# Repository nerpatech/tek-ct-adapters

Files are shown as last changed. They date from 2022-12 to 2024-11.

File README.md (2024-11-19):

# TO-252 Test Fixture Adapter for Tektronix Curve Tracers

Test fixture adapter for Tektronix curve tracers. Fits Tek 576, Tek 577 test fixtures, possibly others.

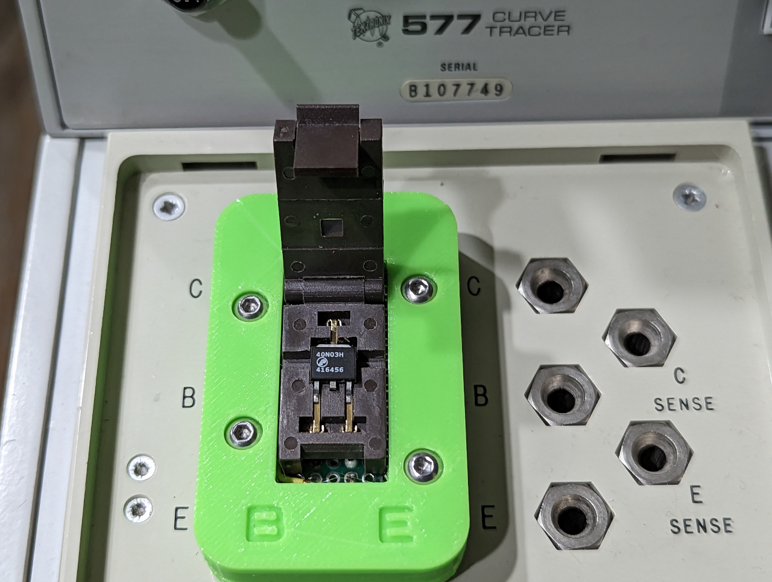
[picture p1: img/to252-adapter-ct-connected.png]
TO-252 adapter plugged into the curve tracer


## Bill Of Materials

| Item | Qty | Source |
| --- | --- | --- |
| Prototype Board, 5x7mm, 0.1 in. hole pitch | 1 |
| 4 mm RC-style banana plugs | 3 |
| 6mm silicone rubber feet | 2 |
| TO-252 burn-in adapter | 1 |
| M3x8mm button head socket screws | 4 |
| M3 nuts | 4 |

## Tools

Drill Press*, 3/16" drill bit*, 3D printer, any rigid filament (PETG, PLA, ABS, etc.), soldering iron, hookup wire.

## Assembly

Printed part models are in 'STL/' folder.
Please also check the 'img/' folder for assembly pictures.

1. Print bottom, middle, and top pieces, as well as two jigs. Printing parameters: 0.6mm or smaller nozzle, 0.3mm or lower
layer height. 

2. Using the drill jig find holes that can be used as pilots for 3mm screws on the prototype board, mark them, remove the jig, then drill 3mm holes where marked.

3. Screw the drill jig to the board, drill 3/16" holes for the banana plugs.

4. Cut the excess material. A drill jig can be used to make the clean edge.

5. Insert banana plugs as shown. Check the height protruding from the other side, should be 1mm*. A leveling jig can be used.

6. Insert* and solder TO252 test socket as shown. Connect the socket pins to the banana plugs.

7. Assemble 3 printed pieces and PCB as shown.

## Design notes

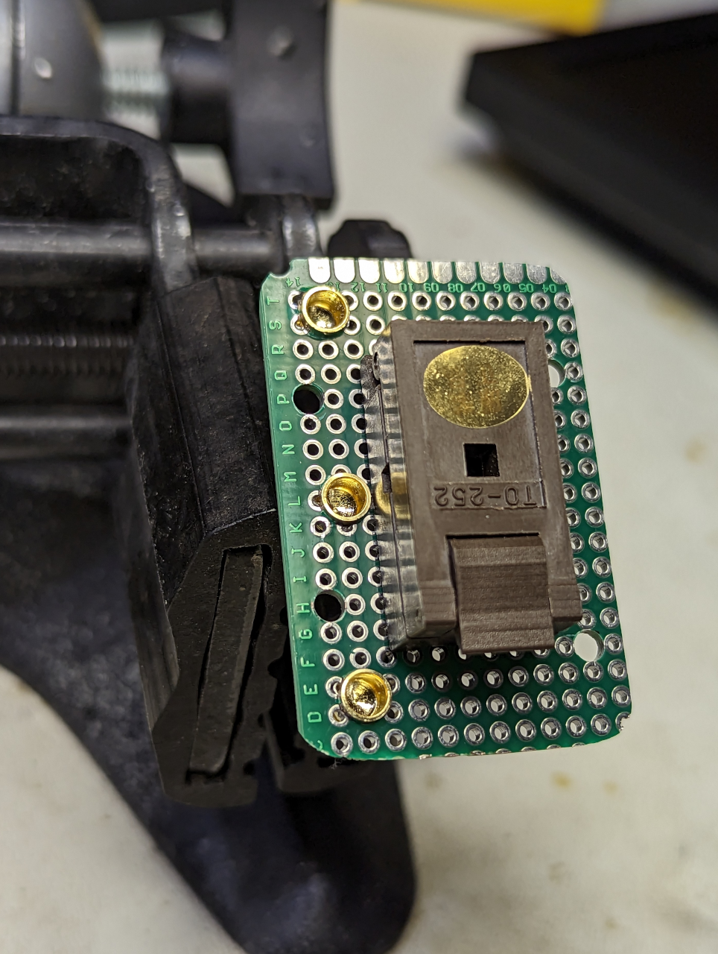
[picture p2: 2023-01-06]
img/to252-socket-try.png

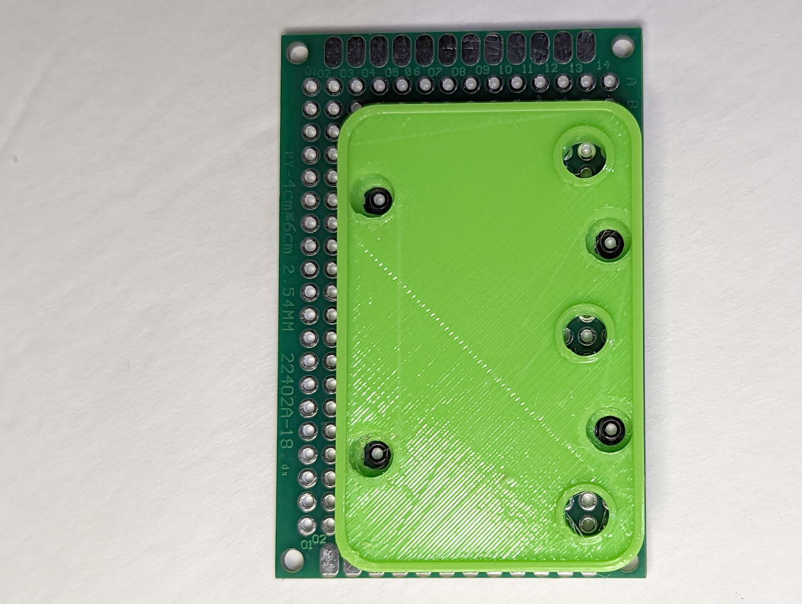
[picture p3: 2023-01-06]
img/to252-drill-jig-and-pcb-aligned.png

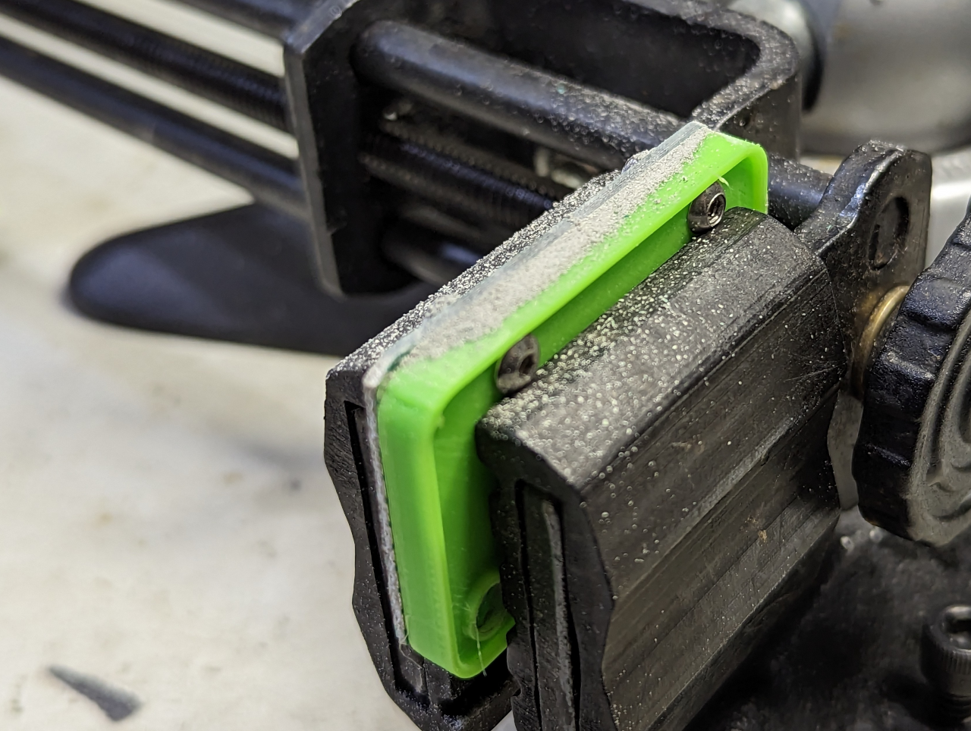
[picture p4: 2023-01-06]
img/to252-pcb-sized.png

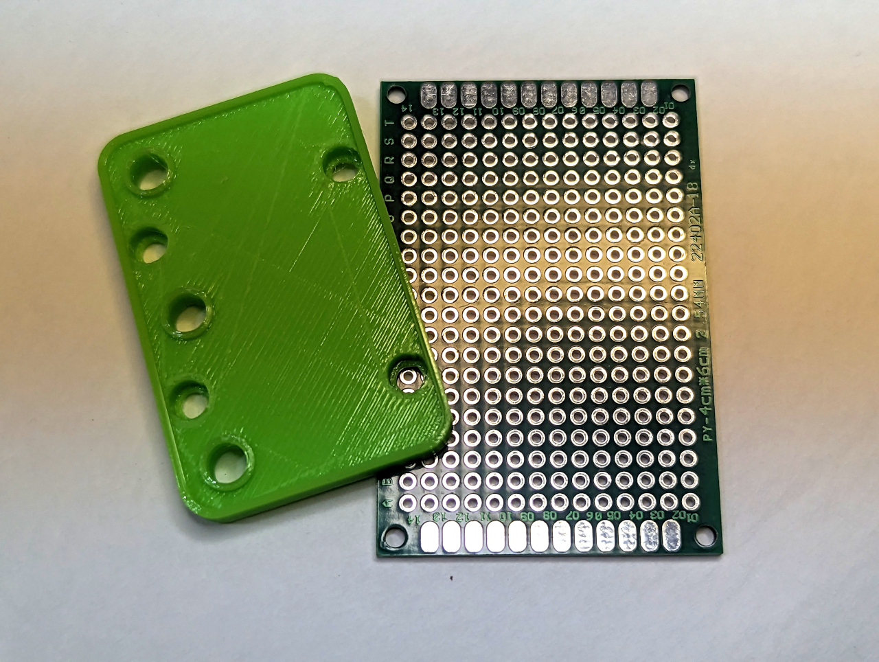
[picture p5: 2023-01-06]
img/to252-drill-jig-and-pcb.png

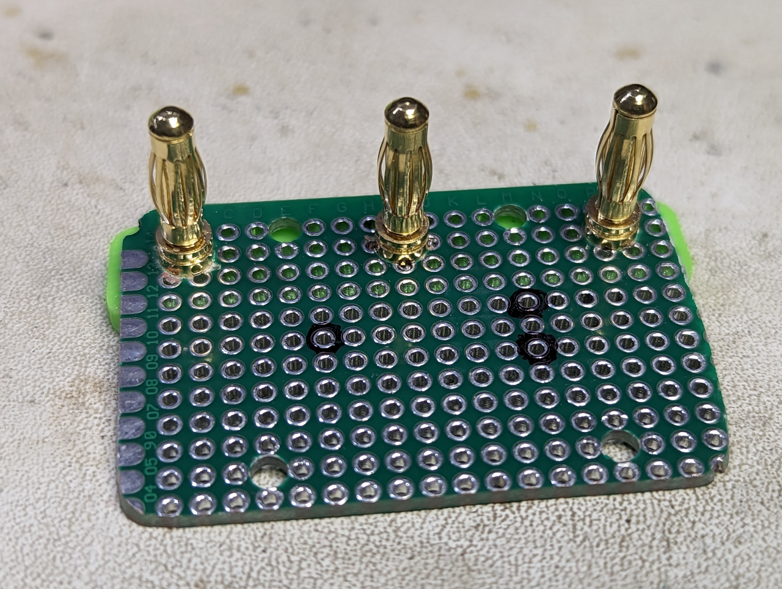
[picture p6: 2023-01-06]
img/to252-banana-plug-inserted-front.png

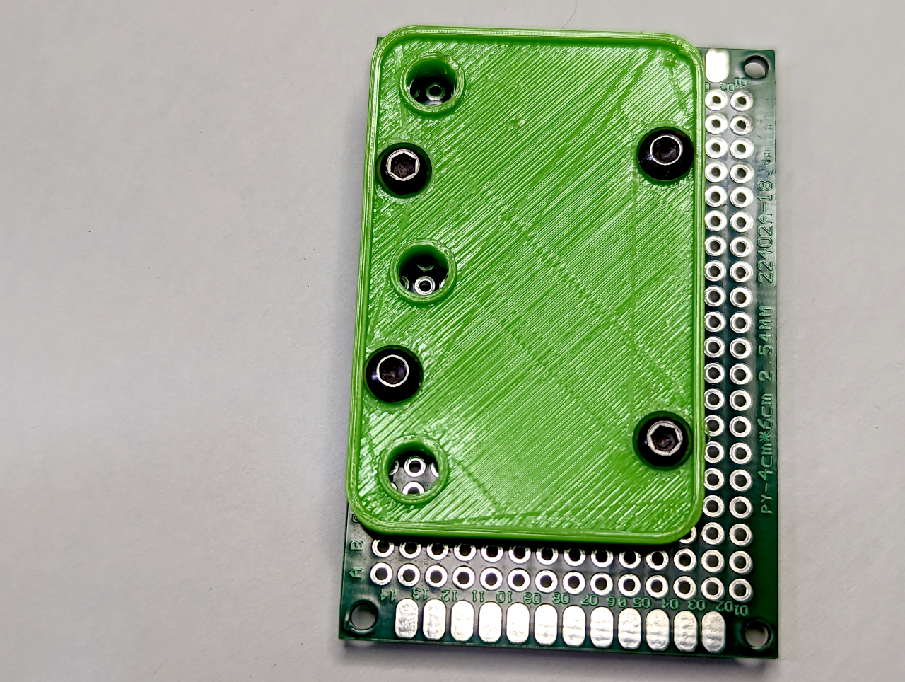
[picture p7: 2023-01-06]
img/to252-drill-jig-and-pcb-screwed-together.png

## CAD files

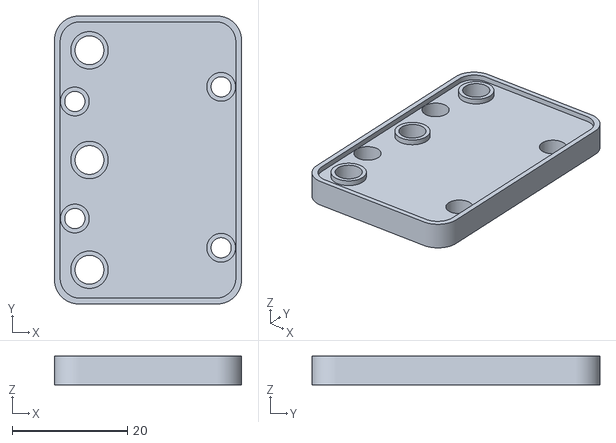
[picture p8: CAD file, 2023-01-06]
STL/3plug-drill-jig.stl
32.5 x 50.0 x 5.00

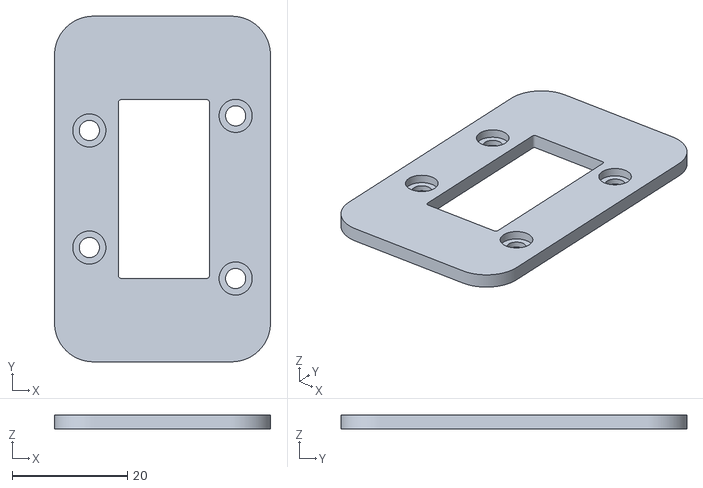
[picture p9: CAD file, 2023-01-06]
STL/3plug-top-var2.stl
37.5 x 60.0 x 2.50

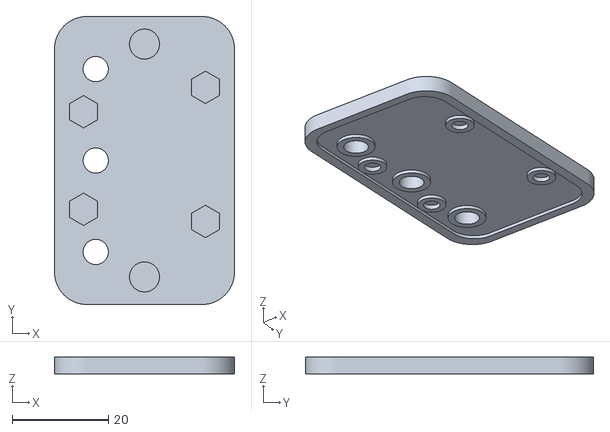
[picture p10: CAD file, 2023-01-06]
STL/3plug-bottom.stl
37.5 x 60.0 x 3.50

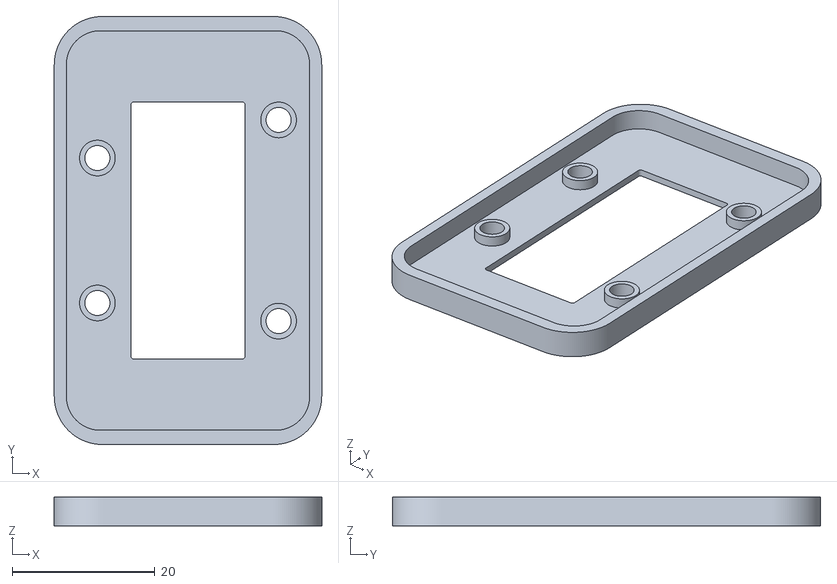
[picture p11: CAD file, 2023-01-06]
STL/3plug-middle-var2.stl
37.5 x 60.0 x 4.00

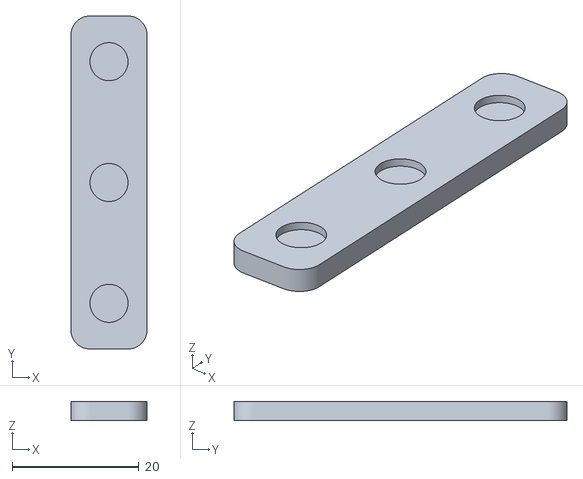
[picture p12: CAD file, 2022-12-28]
STL/3plug-leveling-jig.stl
12.0 x 52.5 x 3.00

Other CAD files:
STL/3plug-top-var2-cbe.stl

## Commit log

2023-01-03 printability tested, added TO-252 label
    [3plug-bottom-hires-to-252.stl]
2023-01-05 added to-252 assembly images
2023-01-05 added to-252 assembly images take 2
2023-01-05 renamed to-252 assembly pictures
2023-01-06 modified STL added
    [3plug-bottom-hires-to-252.stl, 3plug-bottom.stl, 3plug-drill-jig.stl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]
2024-11-19 Update README.md
    Modified BOM
